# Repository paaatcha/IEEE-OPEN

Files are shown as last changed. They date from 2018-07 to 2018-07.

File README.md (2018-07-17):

# IEEE OPEN

The IEEE OPEN is a category of the Latin American Robotic Competition (LARC) in which is allowed to use anything in order to solve a given challenge. In 2013, I led a team with 9 students that participated in this competition in Arequipa, Peru. The competition's rule is described in [this document](). In brief, we needed to develop an **autonomous beach cleaner robot**. This robots had to perform in the simulated arena depicted below:

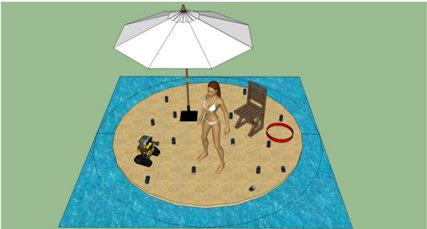
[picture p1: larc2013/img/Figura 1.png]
arena


The robot was entirely designed on the 3D software [OpenScad](http://opensacad.org) and its physical structure was composed of acrylic and 3D printed pieces. In [estrutura folder](https://github.com/paaatcha/IEEE-OPEN/tree/master/larc2013/estrutura) you can see all designed parts.

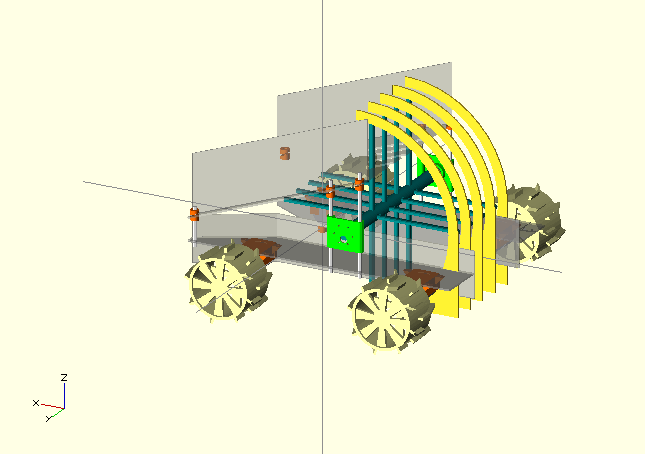
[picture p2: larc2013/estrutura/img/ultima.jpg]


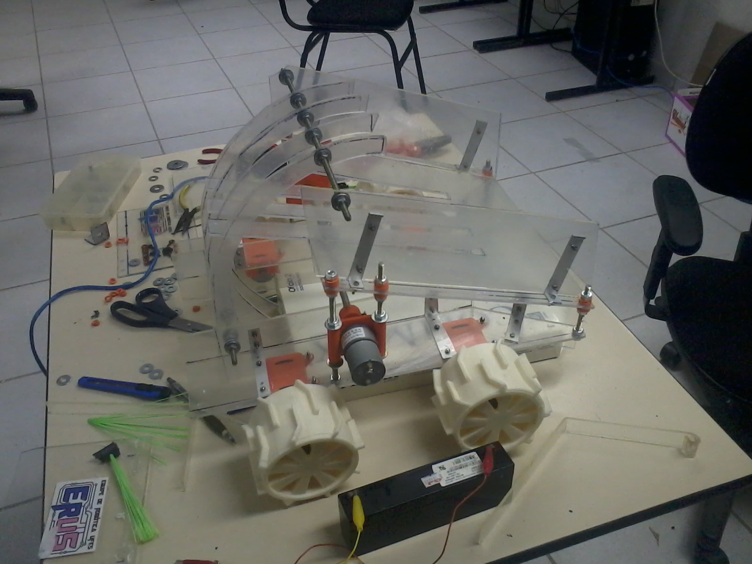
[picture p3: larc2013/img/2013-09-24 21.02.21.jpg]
real


In order to "see" the environment, we used an Android smartphone embedded in the robot and all computer vision was processed on the own Android. We needed to do it for two main reasons: first, we didn't have money to afford a good camera; second, it was an elegant solution since the smartphone fitted perfectly in the robot. To control motors, servo motors, and ultrasonic sensors, we used an Arduino Mega. In brief, the working flow was: the Android gets information for the world through its camera, process it and send the commands to the Arduino. 

To put everything together, we developed a PCB that you can find on [eletronica folder](https://github.com/paaatcha/IEEE-OPEN/tree/master/larc2013/eletronica).

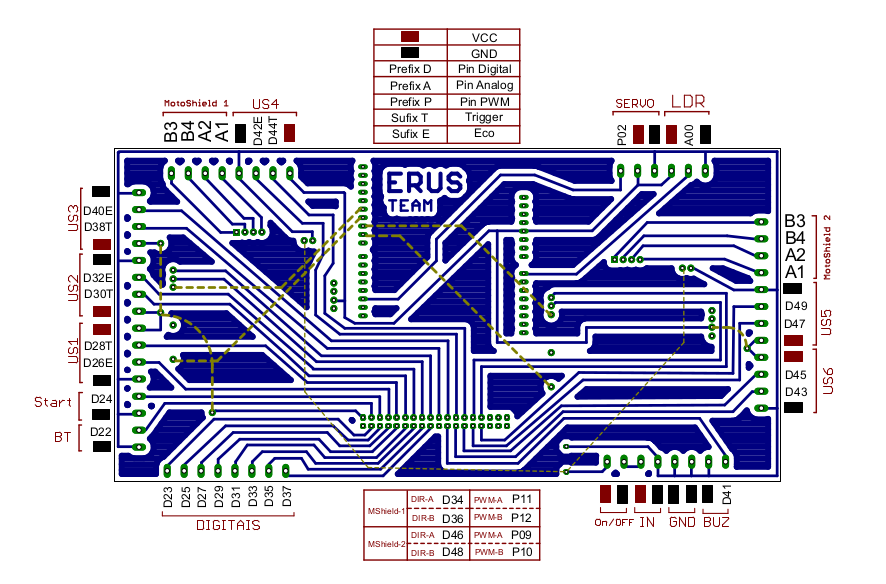
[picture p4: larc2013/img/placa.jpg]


All code developed to this project is avalaible on [programacao folder](https://github.com/paaatcha/IEEE-OPEN/tree/master/larc2013/programacao). We used C/C++ and Java to programmed all parts.

A curious and sad thing that happened to us when we were traveling to Peru was that the airplane company has lost our luggage with many parts of the robot. Therefore, a day and a half before the competition starts, we needed to reconstruct the whole robot from almost scratch. Luckily, all electronic parts arrived, however, we've lost some motors. What we did was buy a lot of things in the local market to reconstruct the robot. Even with this, we were able to get the 2nd place out of 19 teams. No doubt, it was the most exciting story of my life.

The robot version at the competition:

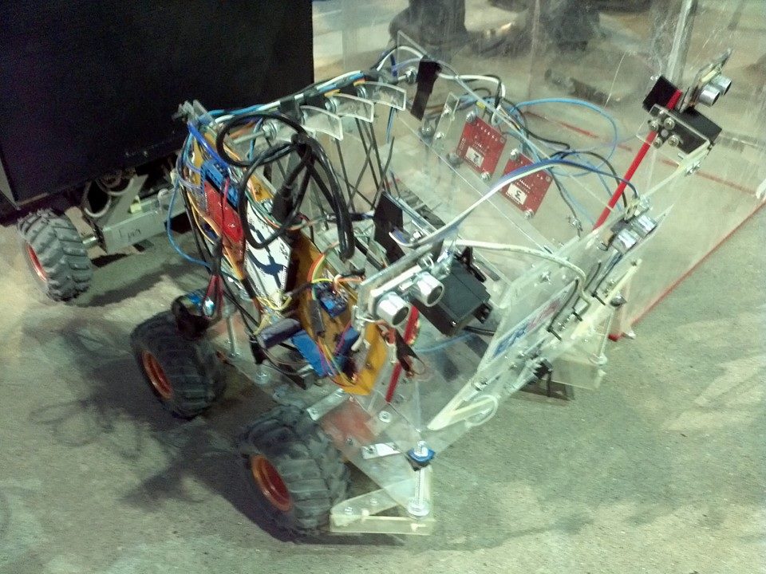
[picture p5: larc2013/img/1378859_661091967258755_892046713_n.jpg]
robo


The team after the 2nd place in the competition:

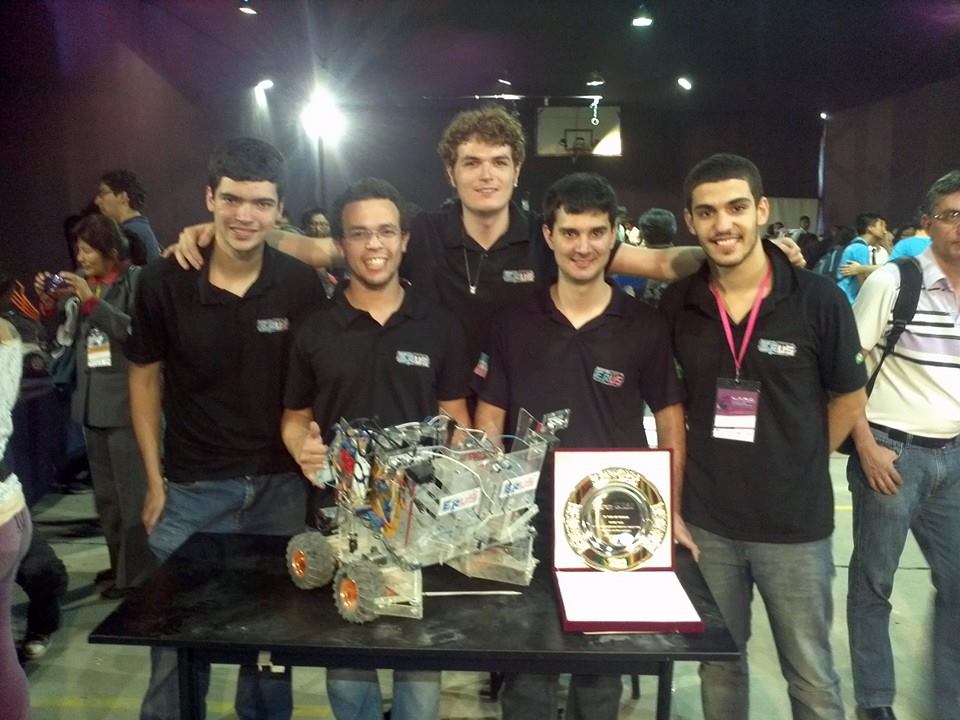
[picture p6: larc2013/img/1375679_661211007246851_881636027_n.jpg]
team


Take a look at the robot perfoming in the competition:

IMAGE ALT TEXT HERE (https://www.youtube.com/watch?v=20euAUzxxZE)

We got famous in our city. Take look at our interview to a local news:

IMAGE ALT TEXT HERE (https://www.youtube.com/watch?v=20b5NIf7TLY)

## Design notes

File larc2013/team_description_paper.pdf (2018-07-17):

ERUS – TEAM DESCRIPTION PAPER – IEEE OPEN 2013

ROBERTA LIMA GOMES¹

, ANDRÉ GEORGHTON CARDOSO PACHECO 1

, LUCAS CATABRIGA ROCHA¹

, JUAN FRANÇA MUNIZ DE
SOUZA¹

, EBENÉZER NOGUEIRA DA SILVA¹

, GUILHERME ARTÉM DOS SANTOS¹

, VANDERLEI VIEIRA DE SOUZA FILHO¹

, RENAN
SARCINELLI¹

, IGOR OLIVEIRA NUNES¹

, THAYLO XAVIER DE FREITAS¹

Departamento de Informática ¹

Centro Tecnológico, Universidade Federal do Espírito Santo Av. Fernando Ferrari 514 – Goiabeiras, Vitória ES

Abstract This article reports the work of the team ERUS building a robot to solve the challenge posed in IEEE Open 2013 category. The robot collects empty cans on an irregular terrain made of sand and deposits them in a trash bin. The system built uses an Android phone connected to an Arduino board.

Keywords Robotics, Android, Arduino.

Resumo Este artigo relata o trabalho desenvolvido pela equipe ERUS na construção de um robô para solucionar o desafio proposto na categoria IEEE Open 2013. O robô construído coleta latas de refrigerante em um terreno irregular feito de areia e as deposita em uma lixeira. O sistema construído é composto por um celular Android conectado a uma placa Arduino.

Palavras-chave Robótica, Android, Arduino, LARC.

### 1 Introdução

O desafio IEEE OPEN 2013 proposto na Competição Latino Americana de Robótica (em inglês Latin American Robotics Competition abreviado por LARC) tem como temática a limpeza de resíduos em uma praia. A arena da competição consiste em uma circunferência de areia cercada por uma região azul que representa o mar, simulando assim uma ilha. Nesta arena um robô, completamente autônomo, deverá coletar latas de alumínio espalhadas pela mesma e depositá-las em uma lixeira também localizada na arena. O robô não poderá tocar em nenhum obstáculos presentes na arena, obstáculos estes que serão: uma cadeira, uma sombrinha de praia e um manequim. Além disso o robô não pode adentrar a região azul, que representa o mar. Caso descumpra uma das normas acima, a equipe sofrerá punições na pontuação final e/ou sofrerá reinício da rodada.
A Equipe ERUS (Equipe de Robótica da Universidade Federal do Espírito Santo), formada por alunos de engenharias da UFES, desenvolveu um robô para solucionar este desafio. O robô, completamente projetado em softwares de desenvolvimento 3D, foi desenvolvido para navegar em ambiente com terreno irregular, assim como os terrenos existentes em praias. Sua estrutura física é composta, principalmente, por peças de acrílico e plástico. A parte eletrônica do robô é composta por um Arduino Mega ADK que se comunica com um celular com sistema operacional Android. Este celular é utilizado como “cérebro” central do robô. Nele são capturadas e processadas as imagens da arena. Para isso, as linguagens de programação utilizadas foram C, C++ e Java.
A seguir são apresentados mais detalhes sobre o desafio e as tecnologias utilizadas no desenvolvimento do robô.

### 2 Objetivo

Este desafio tem como objetivo a construção e programação de um robô que trabalhe de forma completamente autônoma. O robô deve ser capaz de identificar todos os objetos inclusos, tais como: Cadeira, sombrinha, manequim, lixeira e latas. Uma vez identificado o obstáculo, o robô deve possuir inteligência suficiente para discernir quais destes objetos são obstáculos e quais são lixo. Além disso, o robô deverá navegar somente dentro do espaço permitido na arena, ou seja, na areia, e coletar o máximo de latas encontradas. Após coletadas, as mesmas deverão ser depositadas em um lugar específíco demarcado na arena.

### 3 Considerações do Ambiente

O cenário proposto simula uma ilha. Para isso, é construído uma arena, com forma circular, cujo as bordas são demarcadas pela cor azul. O tamnaho total da arena possui 6 metros quadrados. Destes, 5,5 metros quadrados são preenchidos por areia. O restante representa o mar e será preenchido por um material de cor azul.
Como já mencionado, a arena deverá conter latas de alumínio, pintadas de preto, que representarão o lixo da praia (que serão colocadas de forma aleatória por toda a arena); um manequim, que representará um banhista; uma cadeira e um guarda sol, que representarão o material utilizado pelo banhista; e por fim uma bandeja circular vermelha, que representará um depósito de lixo onde as latas de alumínio deverão ser recolhidas e depositadas pelo robô.
Um esboço da arena é representado na figura 1:

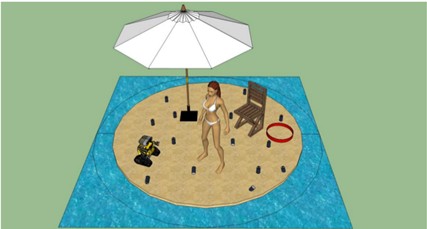
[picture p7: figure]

Figura 1: Arena e seus objetos

Um fator extremamente importante a ser considerado no ambiente é luminosidade do local. A arena poderá estar tanto em um ginásio aberto, e exposta ao sol, quanto em um ginásio fechado. Portanto fica a cargo da equipe solucionar este problema.

### 4 Desenvolvimento do robô

A seguir será apresentado todo o desenvolvimento do robô divido em três partes: Estrutura, Eletrônica e Programação.

4.1 Estrutura do robô
A primeira parte projetada na contrução do robô foi a sua estrutura. Para auxiliar nesta fase, foram utilizados softwares de modelagem 3D como OpensCad [1] e SolidWorks [2]. Portanto, toda estrutura do robô antes de ser físicamente construída foi modelada em 3D para se obter uma melhor performace na construção.

Vale a pena ressaltar que algumas das peças modeladas nos softwares citados acima foram impressas para facilitar a construção física da estrutura. Isso apenas intensifica a importância de uma modelagem 3D antes da construção física.

A estrutura física do robô possui basicamente 3 partes principais: garra, caçamba e a base. Cada uma destas partes será brevemente detalhadas a seguir:
- Garra: A garra do robô consiste, basicamente, em uma “vassoura”. A ideia é que o robô possa “varrer” as latas encontradas para dentro de sua caçamba, para posteriormete depositá-las na lixeira. A garra foi construída utilizando acrílico e peças 3D modeladas e impressas. Para movimentar a garra é utilizado apenas um motor.
- Caçamba: Com intuito de armazenar as latas antes das mesmas serem depositadas, a caçamba do robô foi contruída utilizando acrílico. Esta caçamba foi modelada e con-
truída com uma inclinação de | 20º | para que
possa ser aproveitada a gravidade para as latas caírem. Sendo assim, o único movimento necessário para depositar as latas é abrir a comporta traseira que as prendem. Para isso é utilizado um servo motor que realiza o movimento necessário para abrir e fechar a comporta.
- Base: Toda base do robô também foi construída com acrílico. A base sustenta toda estrutura do robô, como a caçamba e a garra citadas acima. Também, nela, são posicionados toda eletrônica, motores e celular pertinentes ao robô.

Como o robô deverá se movimentar em terreno irregular, ele foi construído com tração 4x4 para evitar que o mesmo fique preso em alguma irregularidade da arena.

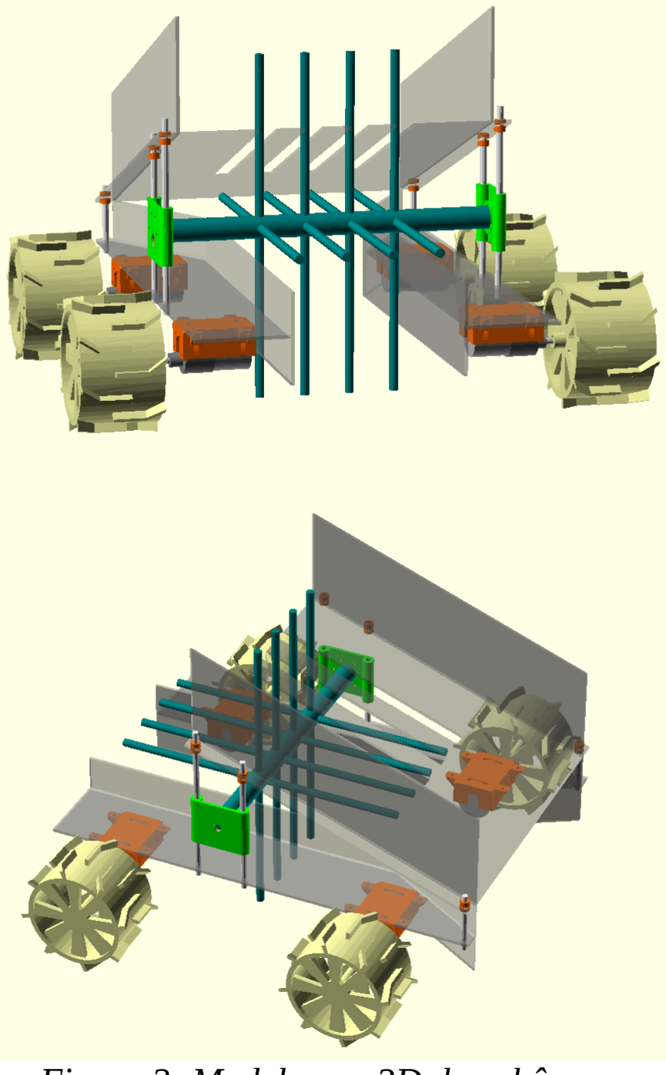
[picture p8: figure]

Figura 2: Modelagem 3D do robô

4.2 Eletrônica
Paralelamente a estrutura, foi desenvolvido toda eletrônica do robô. Para controlar o robô foram utilizados um Arduino Mega ADK [3] e um Celular com Android [4] conectados. A ideia principal é processar a imagem do ambiente no Android e, baseado, nesse processamento enviar as informações para Arduino para que este comande os movimentos do robô.

4.2.1 Arduino
Como já mencionado foi utilizado um microprocessador Arduino Mega ADK para realizar as operações de baixo nível necessárias para o funcionamento do robô. A grande vantagem deste microcontrolador é que ele já implementa uma interface de comunicação USB evitando, assim, a utilização de um shield USB [5] para a comunicação com o Android.
O Arduino é responsável por controlar todos os motores, servo motor, sensores de distância, bem como os botões de on/off e start. Sendo assim, para movimentação dos motores elétricos foi necessário a utilização de duas pontes H, definindo assim a direção dos mesmos.
O controle executado pelo Arduino sofre forte influência das informações de imagens processadas pelo Android. De certo modo, pode-se afirmar que existe uma relação de Mestre e Escravo entre o Arduino e o Android. O Arduino obedece os comandos enviados pelo Android, podendo apenas realizar interrupções geradas pelos sensores de distância, caso o mesmo consiga detectar um obstáculo não encontrado pela câmera.

4.2.2 Android
Aparelhos celulares modernos possuem grande poder de processamento, além disso possuem vários sensores embutidos, como uma câmera de vídeo, bússola e acelerômetro. Isto cria uma ambiente poderoso para o desenvolvimento de robôs móveis e por conta disso este sistema foi escolhido pela ERUS como sistema principal a ser utilizado no robô. O celular utilizado foi um Motorola Milestone I, rodando Android v2.2.
O Android recebe periodicamente valores dos sensores de bússola e acelerômetro além de processar a imagem capturada pela câmera de vídeo existente no celular. De acordo com as informações processadas, o Android envia as ordens para o Arduino por meio de uma troca de informações e um protocolo criado pela equipe.

4.3 Programação
Nesta seção será apresentado tudo o que tange a programação no desenvolvimento do robô. Fica a cargo da programação o controle do Android e do Arduino e a comunicação de ambos. Além disso, aqui é criada uma interface de comunicação entre o Android e um computador, denominado Fiscal. Como o próprio nome sugere, o Fiscal é utilizado como uma fonte de auxílio para depuração de erros e deve se deixar bem claro que essa funcionalidade não é utilizada durante a execução oficial do robô, que funciona de maneira completamente autônoma. Para criar todas as funcionalidade citadas acima, foi necessário desenvolvimento nas seguintes linguagens de programação: C e C++, para o desenvolvimento no Arduino, e Java, para desenvolvimento no Android e Fiscal.

4.3.1 Comunicação Arduino - Android
A comunicação entre o Arduino e o Android ocorre através de um cabo USB. Essa comunicação é facilitada pelo fato do modelo do Arduino utilizado já realizar uma interface de comunicação USB sem necessidade de eletrônica adicional.
O celular Android suporta o ADB (em inglês Android Debug Bridge) [6], uma ferramenta capaz de se comunicar com o Android através da interface USB. Para que o Arduino seja capaz se de comunicar com o ADB, é necessário implementar um protocolo de comunicação em baixo nível. Este protocolo é implementado pela biblioteca MicroBridge
[7] e, portanto, foi utilizada no código de comunicação entre as duas tecnologias.
Nesta configuração a conexão é vista como uma conexão padrão através de um Socket pelo código que roda no Android. No Arduino, a conexão é realizada através de funções da MicroBridge. Além do protocolo implementado pela MicroBridge, é necessário, ainda, um outro protocolo de comunicação básico, porém, mais alto nível. Este último protocolo foi elaborado para que mensagens fossem trocadas entre o Android e o Arduino.

4.3.2 Comunicação Android – Computador
Como já descrito, esta conexão não é utilizada no momento da competição, e sim na depuração de erros, monitoramento dos sensores do robô durante os treinos e calibração de valores. Decidiuse implementar esta funcionalidade para facilitar o desenvolvimento e acelerar a calibração de valores. É possível gravar dados de calibração em um cartão SD no celular através da conexão com o computador e, assim, quando o robô estiver operando autonomamente o cartão SD é lido e os últimos dados enviados pelo computador são utilizados. Também é possível executar o robô em um modo de monitoramento, no qual todos os valores de sensores e variáveis importantes são enviadas ao computador, sendo possível observar possíveis falhas em tempo real.
Para esta finalidade foi desenvolvida, em Java, uma interface gráfica de monitoramento denominada Fiscal. O meio utilizado para esta comunicação é a interface Wireless disponível no celular e em computadores. O protocolo utilizado é o mesmo que protocolo criado para troca de mensagens entre o Arduino e o Android, sendo que algumas mensagens podem ser repassadas desde o Arduino até o computador e vice-versa.

4.3.3 Visão Computacional

A visão computacional é toda realizada dentro do celular Android. Entretanto, o Android não possui nenhuma biblioteca para tratamento de imagens. Sendo assim, se fez necessário a utilização da biblioteca OpenCV para Android [8].
Para o processamento da imagem, é necessário a implementação de algoritmos que identifiquem os objetos que estão na arena. Para auxiliar neste ponto, a equipe utilizou o Color Blob Detector, um algoritmo que é capaz de detectar as diferentes cores nas imagens.
Inicialmente, ao se receber a imagem, é realizada uma conversão de RGB para HSV para facilitar o processamento da mesma. São especificadas as cores a serem reconhecidas a um raio mínimo préestabelecido. Após a identificação é retornado a imagem com os objetos detectados atraveś de um contorno.
Identificado o ambiente, o Android deve tomar decisões sobre o mesmo: Continuar a explorar, coletar lata, depositar lata, dentre outras decisões possíveis. Tomada essa decisão, uma mensagem de ordem é enviada ao Arduino e logo após executada pelo robô.

### 5 Conclusão

Com o avanço da tecnologia, os celulares estão se tornando mais poderosos, em nível de processamento, e também cada vez mais completos, visto que neles há inserção de vários sensores. O uso integrado de celulares com sistemas operacionais, como o Android, e microcontroladores, como o Arduino, demostrou ser bastante eficiente e confiável para o desenvolvimento de robótica autônoma. Além disso, a utilização de um celular também demostrou ser uma opção com um ótimo custo benefício, devido ao fato do mesmo já possuir diversos sensores que se fossem adquiridos de forma separada aumentaria, e muito, o custo total do projeto. Por fim, pode-se afirmar, devido aos fatos já expostos, que a a robótica tem se tornado mais acessível para a maioria das pessoas.

Referências Bibliográficas

[1] http://www.openscad.org/
[2] http://www.solidworks.com/
[3] http://arduino.cc/en/Main/ArduinoBoardADK
[4] http://www.android.com/

[5]http://www.circuitsathome.com/products-page/ar-
| duino-shields/usb-host-shield-2-0-for-arduino (http://www.circuitsathome.com/products-page/arduino-shields/usb-host-shield-2-0-for-arduino)
[6] http://developer.android.com/tools/help/adb.html
[7] http://code.google.com/p/microbridge/
[8] http://opencv.org/platforms/android.html

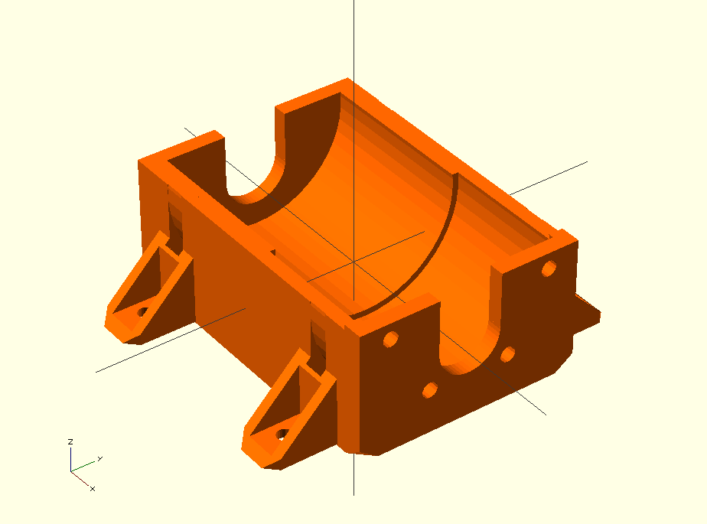
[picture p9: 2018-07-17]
larc2013/estrutura/img/suporteMotor.png

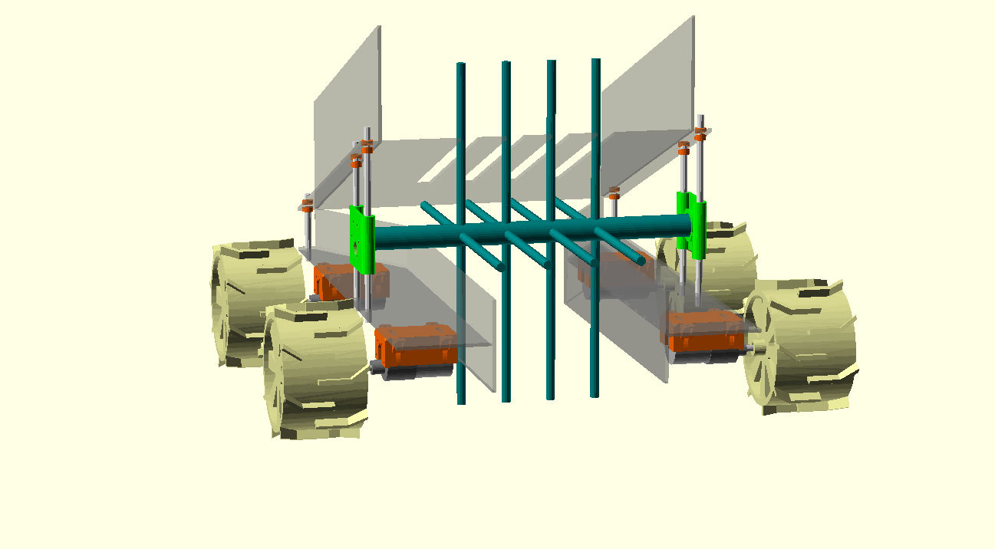
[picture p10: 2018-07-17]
larc2013/img/1498749_768988053135812_4544890504547737136_o.png

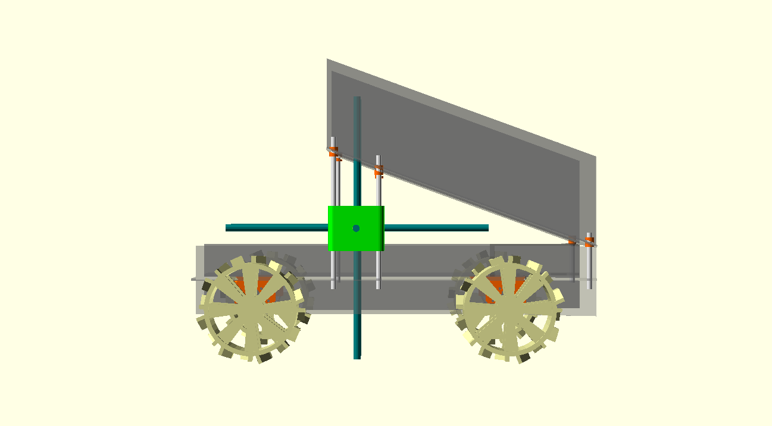
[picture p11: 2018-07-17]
larc2013/estrutura/img/polipo2.png

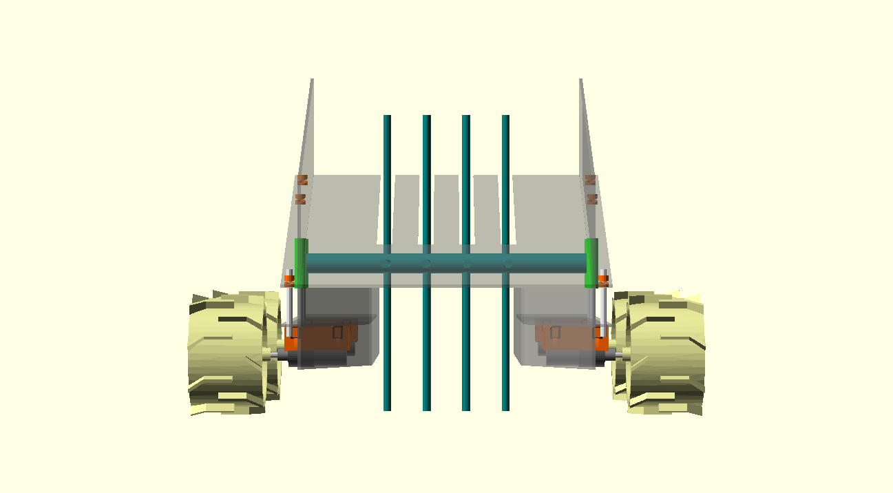
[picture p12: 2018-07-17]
larc2013/estrutura/img/polipo3.png

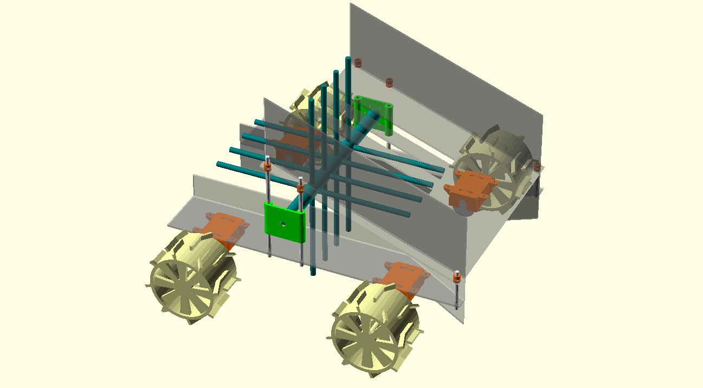
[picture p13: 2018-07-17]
larc2013/estrutura/img/polipo7.png

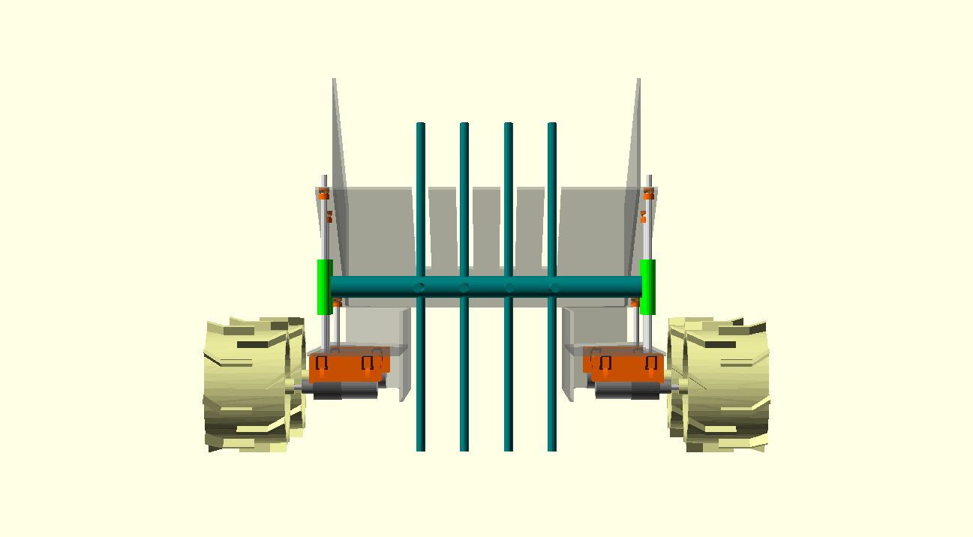
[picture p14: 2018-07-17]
larc2013/estrutura/img/polipo4.png

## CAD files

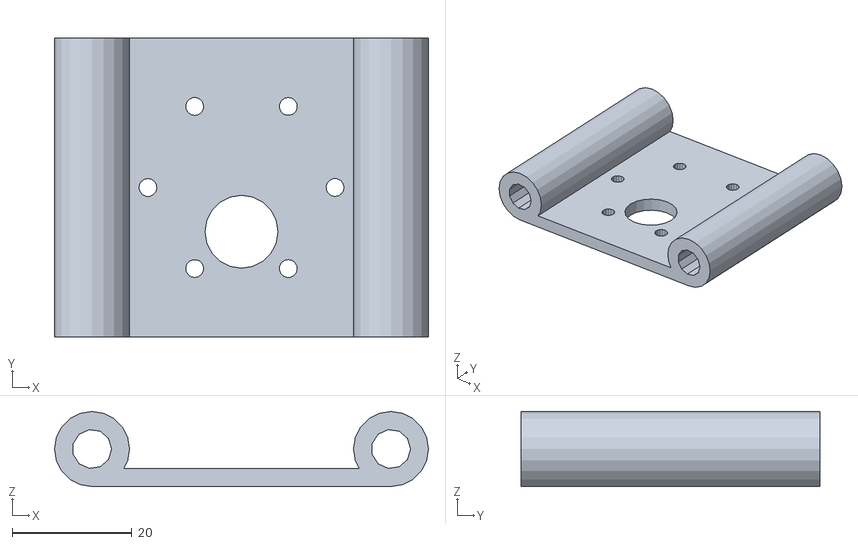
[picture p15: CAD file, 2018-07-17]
larc2013/estrutura/suporteMotorVassoura.stl
62.5 x 50.0 x 12.6

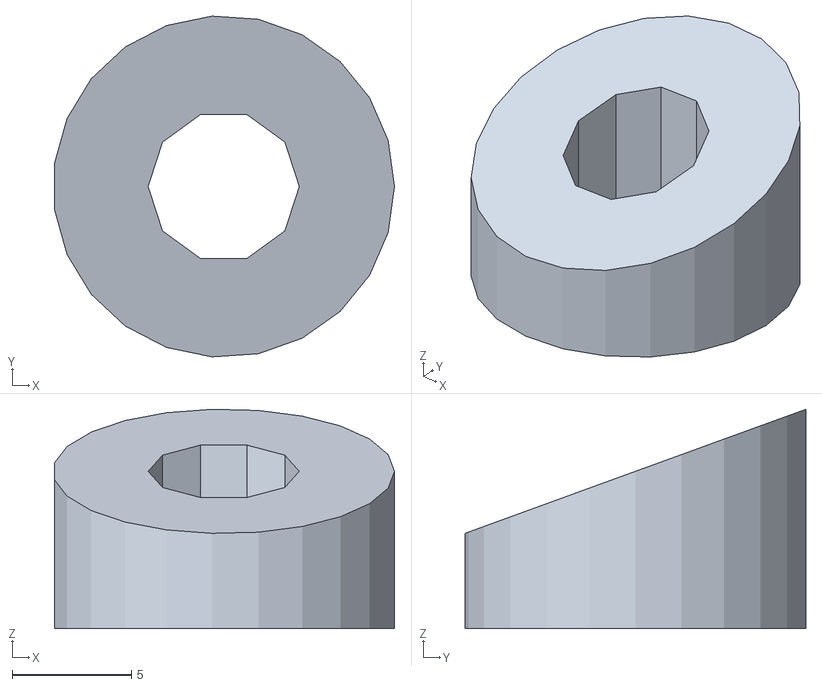
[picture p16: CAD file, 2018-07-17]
larc2013/estrutura/arruelaInclinada.stl
14.3 x 14.3 x 9.22

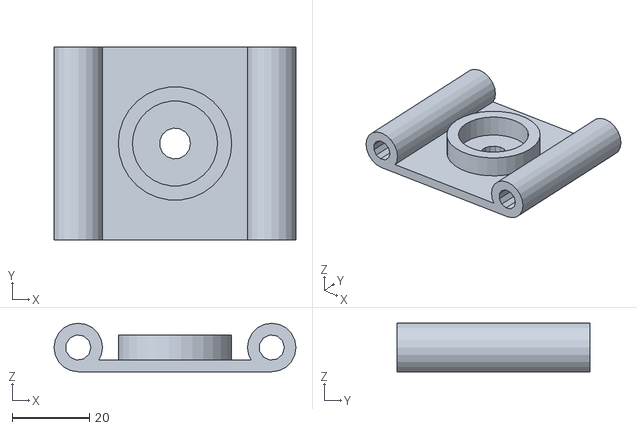
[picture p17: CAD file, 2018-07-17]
larc2013/estrutura/suporteRolamentoVassoura.stl
62.5 x 50.0 x 12.6

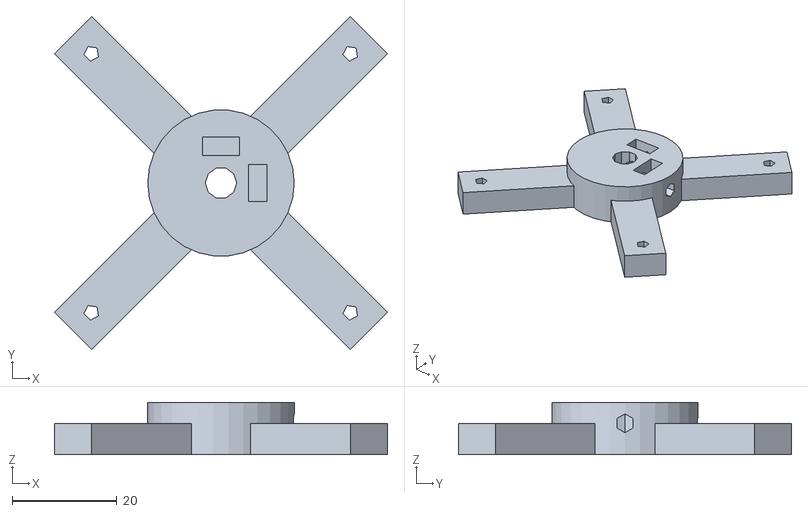
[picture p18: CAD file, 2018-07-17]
larc2013/estrutura/wheelAdapter.stl
63.6 x 63.6 x 10.0

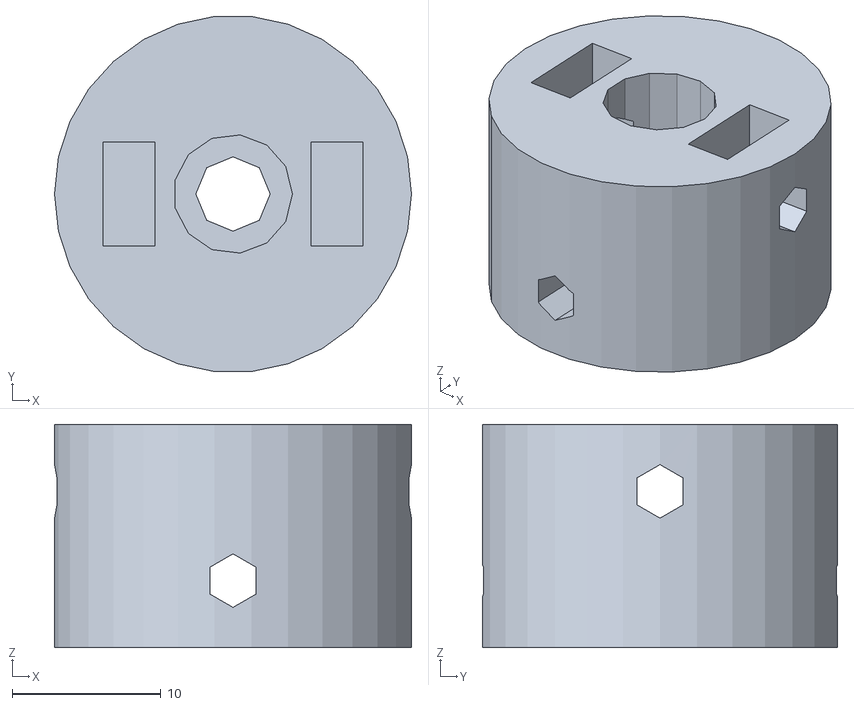
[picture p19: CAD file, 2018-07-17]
larc2013/estrutura/AxisConnector.stl
24.0 x 23.9 x 15.0

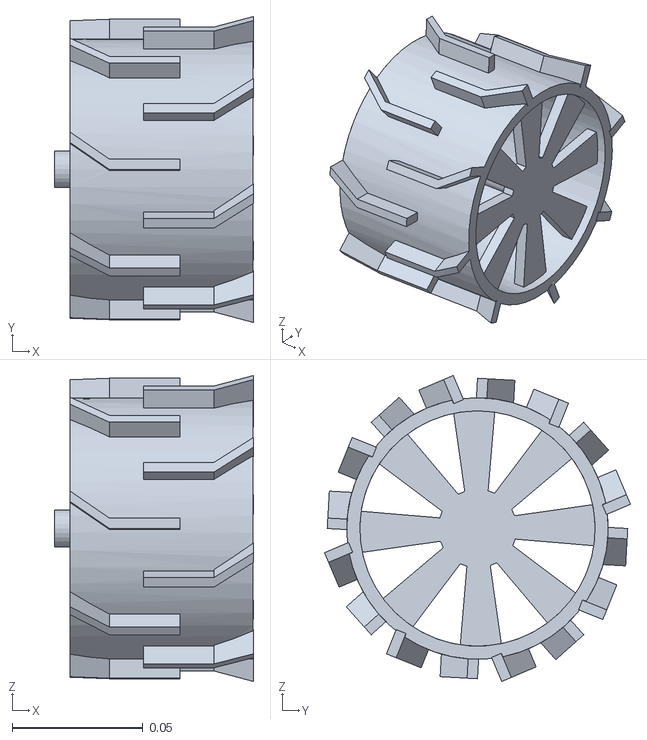
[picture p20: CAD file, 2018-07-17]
larc2013/estrutura/Roda.stl
0.0761 x 0.117 x 0.117

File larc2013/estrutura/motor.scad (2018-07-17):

include <medidas.scad>

motorLength= MOTOR_LENGTH1 + MOTOR_LENGTH2; 
motorShaftDisplacement= [-7.4, 0 , motorLength/2]; 

module motor()
{
	color([0.7,0.7,0.7])
	{
		translate([0,0,MOTOR_LENGTH1/2])
		{
			cylinder(h = MOTOR_LENGTH2+0.015, r = MOTOR_DIAMETER2/2.0, center = true, $fn=50);
		}
	}
	color([0.5,0.5,0.5])
	{
		translate([0,0,-MOTOR_LENGTH2/2])
		{
			cylinder(h = MOTOR_LENGTH1, r = MOTOR_DIAMETER1/2.0, center = true, $fn=50);
		}
	}

	color([0.5,0.5,0.5])
	{
		scale([1,1,-1])
		{
			translate(motorShaftDisplacement)
			{
				cylinder(h = MOTOR_SHAFT_LENGTH, r = MOTOR_LARGE_SHAFT_DIAMETER/2, center=true, $fn=25);
			}
		}
	}

		color([0.8,0.8,0.8])
	{
		scale([1,1,-1])
		{
			translate(motorShaftDisplacement+[0,0,MOTOR_SHAFT_LENGTH])
			{
				eixo();
			}
		}
	}
}

module eixo ()
{
	rotate([0,0,360*$t])
	{
		difference()
		{
			cylinder(h = MOTOR_BIGGER_SHAFT_LENGTH, r = MOTOR_SHAFT_DIAMETER/2, center=true, $fn=20);
			translate([MOTOR_SHAFT_DIAMETER_CUT,0,0])
			{
				cube([MOTOR_SHAFT_DIAMETER,MOTOR_SHAFT_DIAMETER,1.1*MOTOR_BIGGER_SHAFT_LENGTH], center=true);
			}
		}
	}
}

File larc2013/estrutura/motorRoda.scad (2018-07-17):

include <motor.scad>
include <suporteMotor.scad>
include <medidas.scad>

module suporteMotor ()
{
	motormount();
	translate([-MOTOR_DIAMETER1/4,0,0])
	rotate([0,180,180])
	{
		motor();
	}
}

module motorRoda()
{
	suporteMotor();
	translate([-MOTOR_DIAMETER1/4-7.4,0,(MOTOR_LENGTH1+MOTOR_LENGTH2)/2+MOTOR_BIGGER_SHAFT_LENGTH/2+WHEEL_WIDTH/2])
	{
		rotate([-90-360*$t,-90,0])
		{
			scale([1000,1000,1000])
			{
				color([0.9,0.9,0.6])
				{
					import ("Roda.stl");
				}
			}
		}
	}
}

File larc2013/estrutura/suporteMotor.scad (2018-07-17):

include <medidas.scad>

diameter = MOTOR_DIAMETER1;
diameter2 = MOTOR_DIAMETER2;
diameterLength = MOTOR_LENGTH1;
diameter2Length = MOTOR_LENGTH2;
shaftLength = MOTOR_SHAFT_LENGTH;
suporteMotorLength = diameterLength + diameter2Length; 
shaftDiameter = MOTOR_SHAFT_DIAMETER;
largeShaftDiameter = MOTOR_LARGE_SHAFT_DIAMETER;
suporteMotorShaftDisplacement = [-7.4, 0 , suporteMotorLength/2]; 
screwDiameter = MOTOR_SCREW_SUPORT_DIAMETER;
screw2Diameter = MOTOR_SCREW_MOTOR_DIAMETER;
pinDiameter = 20;
pinHeight = 10;
zipLockThickness = MOTOR_ZIPLOCK_THICKNESS;
zipLockWidth = MOTOR_ZIPLOCK_WIDITH; 

module motormount()
{	
	color([1,0.4,0])
	{
		difference()
		{
			union()
			{
				rotate([0,180,0])
				{
					difference()
					{
						union()
						{
							rotate([0, 90, 0])
							{
								printCube(suporteMotorLength +6, diameter+5,(diameter/2) +5 , 5);
							}
							translate([diameter/2-8,0,-suporteMotorLength/2-1])
							cube([4,diameter+5,4],center=true);
						}
						translate([10, 0, 0])
						{
							motorSpace();
						}
					}
				}
	
				screwSupport(-20);
				screwSupport(20);
			}
			translate([-10,0,20])
			{
				ring((diameter/2)+2.5, zipLockThickness, zipLockWidth);
			}
			translate([-10,0,-20])
			{
				ring((diameter/2)+2.5, zipLockThickness, zipLockWidth);
			}
		}
	}
}

module ring(radius, thickness, width)
{
	difference()
	{
		cylinder(r= radius+thickness, h = width, center=true, $fn=50);
		cylinder(r= radius, h= width*2, center=true, $fn=50);
	}
}

module uHole(radius, height)
{
	cubeLength = 1000;
	cylinder(h = height, r = radius, center=true, $fn=50);
	translate([cubeLength/2, 0, 0])
	{
		cube([cubeLength, 2*radius, height], center=true);
	}
}

module triangle(cateto, width)
{
	rotate([0, 0, 90])
	{
		difference()
		{
			cube([cateto, cateto, width], center = true);

			translate([cateto/2, cateto/2, 0])
			{
				rotate([0, 0, 45])
				{
					cube([cateto*sqrt(2), cateto*sqrt(2), width+1], center=true);
				}
			}
		}
	}
}

module screwSupportTriangle(z)
{
	translate([5.25, diameter-10, z])
	{
		triangle(13, 10);
	}

	scale([1,-1,1])
	{
		translate([5.25, diameter-10, z])
		{
			triangle(13, 10);
		}
	}
}

module screwSupportCube(z)
{
	translate([0, diameter-15, z-3])
	{
		cube([10, 10, 6]);
	}

	scale([1,-1,1])
	{
		translate([0, diameter-15, z-3])
		{
			cube([10, 10, 6]);
		}
	}
}
module screwSupportCylinder(z)
{
	translate([0, diameter-10, z])
	{
		rotate([0, 90, 0])
		{
			cylinder(h = 15, r = screwDiameter/2, $fn=20);
		}
	}
	scale([1,-1,1])
	{
		translate([0, diameter-10, z])
		{
			rotate([0, 90, 0])
			{
				cylinder(h = 15, r = screwDiameter/2, $fn=20);
			}
		}
	}
}

module screwSupport(z, screwDiameter)
{
	difference()
	{
		difference()
		{
			screwSupportTriangle(z);
			screwSupportCube(z);
		}
		translate([0,0,-0.3])
		{
			rotate([45,45,-135])
			{
				cube([d,d,d], center =true);
			}
		}
		
		screwSupportCylinder(z);
		
		translate([0,((diameter+5)/2)+13,-5+z])
		{
			rotate([45,0,0])
			{
				cube([300,3,3], center =true);
			}
		}
			
		translate([0,((diameter+5)/2)+13,5+z])
		{
			rotate([45,0,0])
			{
				cube([300,3,3], center =true);
			}
		}

		translate([0,-((diameter+5)/2)-13,-5+z])
		{
			rotate([45,0,0])
			{
				cube([300,3,3], center =true);
			}
		}
			
		translate([0,-((diameter+5)/2)-13,5+z])
		{
			rotate([45,0,0])
			{
				cube([300,3,3], center =true);
			}
		}
	}
}

module motorSpace()
{
	translate([0,0,diameterLength/2])
	{
		cylinder(h = diameter2Length+0.015, r = diameter2/2.0, center = true, $fn=50);
	}

	translate([0,0,-diameter2Length/2])
	{
		cylinder(h = diameterLength, r = diameter/2.0, center = true, $fn=50);
	}

	color([1.0,0,0])
	{
		translate(suporteMotorShaftDisplacement)
		{
			uHole(radius=largeShaftDiameter/2, height=10);
		}

		scale([1,1,-1])
		{
			translate(suporteMotorShaftDisplacement)
				{
					uHole(radius=largeShaftDiameter/2, height=10);
				}
		}
		for(i=[1:6])
		{
		rotate([0,0,60*i])
			{
				translate([0,15.65,-diameter2Length])
				{
				cylinder (r=screw2Diameter/2,h= diameterLength,center=true,$fn=15);
				}
			}	
		}
	}
}

module printCube(a,b,c,d)
{
	translate([a,b,c]/-2)
	difference()
	{
	cube([a,b,c]);
	
	translate([0,0,-0.2*d])
	rotate([45,45,-135])
	cube([d,d,d], center =true);

	translate([0,b,-0.2*d])
	rotate([45,45,135])
	cube([d,d,d], center =true);

	translate([a,b,-0.2*d])
	rotate([45,45,45])
	cube([d,d,d], center =true);

	translate([a,0,-0.2*d])
	rotate([45,45,-45])
	cube([d,d,d], center =true);
	}
}

rotate([0,90,0])
motormount();

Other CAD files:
larc2013/estrutura/suporteMotorVassoura.scad
larc2013/estrutura/AxisConnector.scad
larc2013/estrutura/Polipo.scad
larc2013/estrutura/RodaRefletida.scad
larc2013/estrutura/arruelaInclinada.scad
larc2013/estrutura/base.scad
larc2013/estrutura/bigBattery.scad
larc2013/estrutura/halfMoon.scad
larc2013/estrutura/halfMoon3D.scad
larc2013/estrutura/half_moon.scad
larc2013/estrutura/half_moon_3D.scad
larc2013/estrutura/inclinacao.scad
larc2013/estrutura/medidas.scad
larc2013/estrutura/paredeBase.scad
larc2013/estrutura/rampa.scad
larc2013/estrutura/smallBattery.scad
larc2013/estrutura/suporteRolamentoVassoura.scad
larc2013/estrutura/vassoura.scad
larc2013/estrutura/wheelAdapter.scad

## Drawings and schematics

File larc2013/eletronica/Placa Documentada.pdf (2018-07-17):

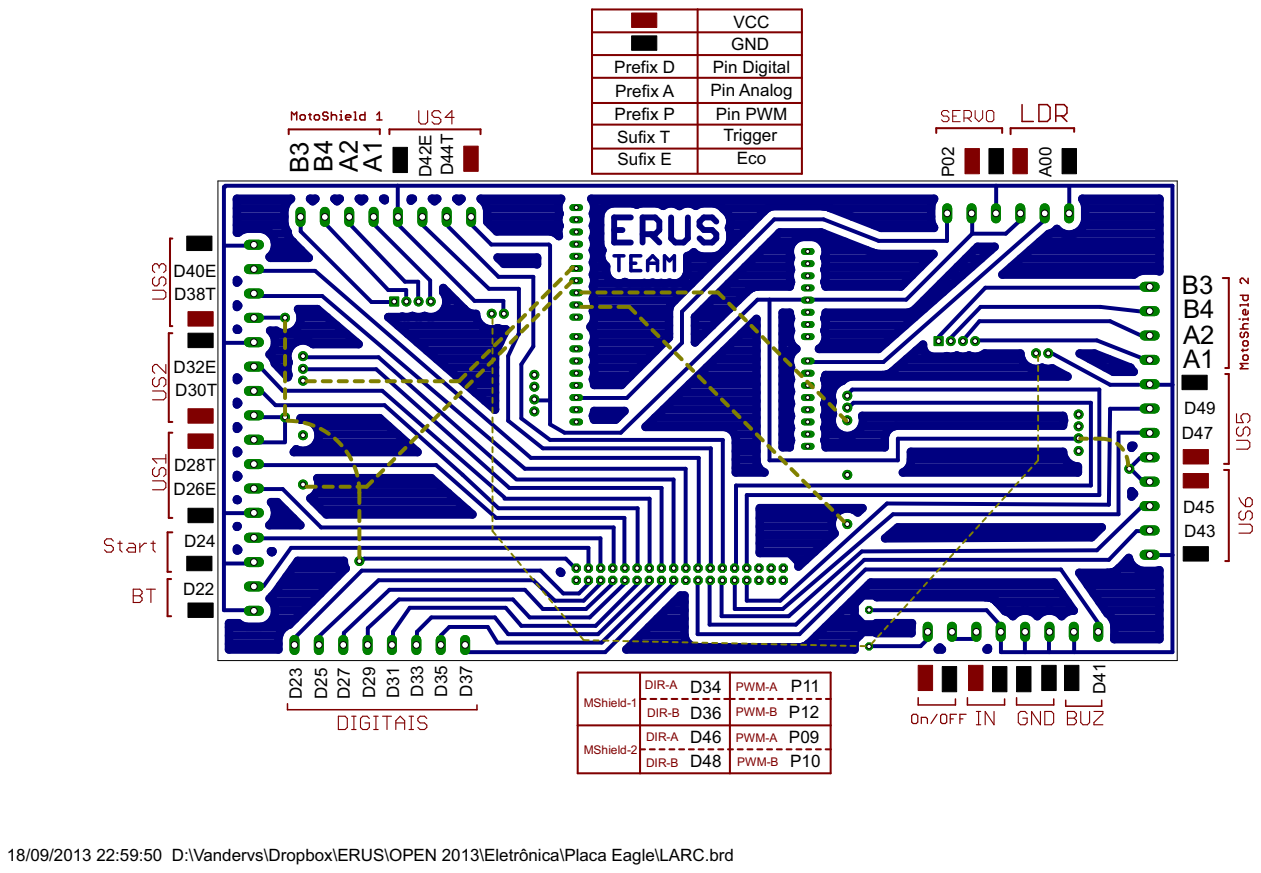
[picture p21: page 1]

VCC
GND

Prefix D | Pin Digital
Prefix A | Pin Analog
Prefix P | Pin PWM
Sufix T | Trigger
Sufix E | Eco

MShield-1 | DIR-A D34 DIR-B D36 | PWM-A P11 PWM-B P12

MShield-2 | DIR-A D46 D48 DIR-B | PWM-A P09 P10 PWM-B

18/09/2013 22:59:50 D:\Vandervs\Dropbox\ERUS\OPEN 2013\Eletrônica\Placa Eagle\LARC.brd

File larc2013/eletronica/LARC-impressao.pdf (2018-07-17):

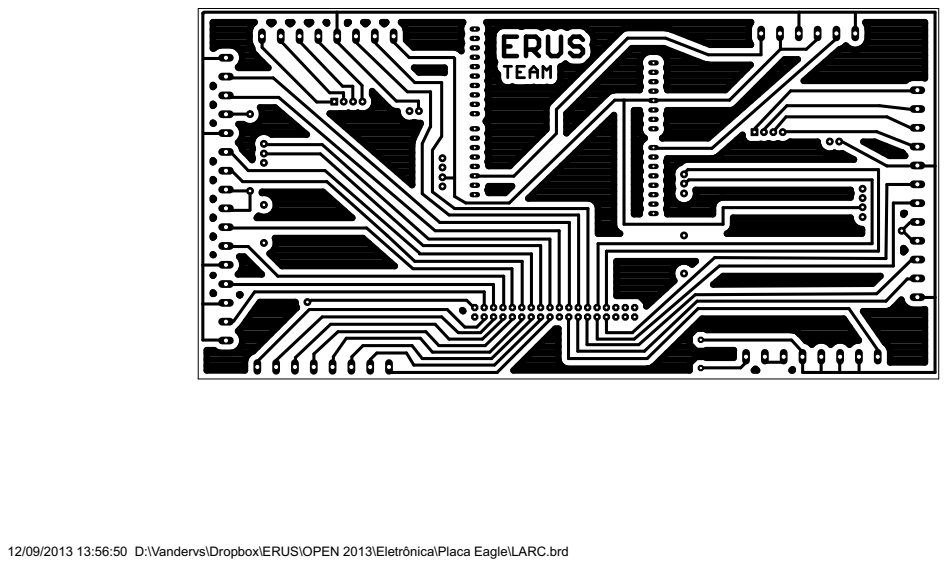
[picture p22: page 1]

12/09/2013 13:56:50 D:\Vandervs\Dropbox\ERUS\OPEN 2013\Eletrônica\Placa Eagle\LARC.brd

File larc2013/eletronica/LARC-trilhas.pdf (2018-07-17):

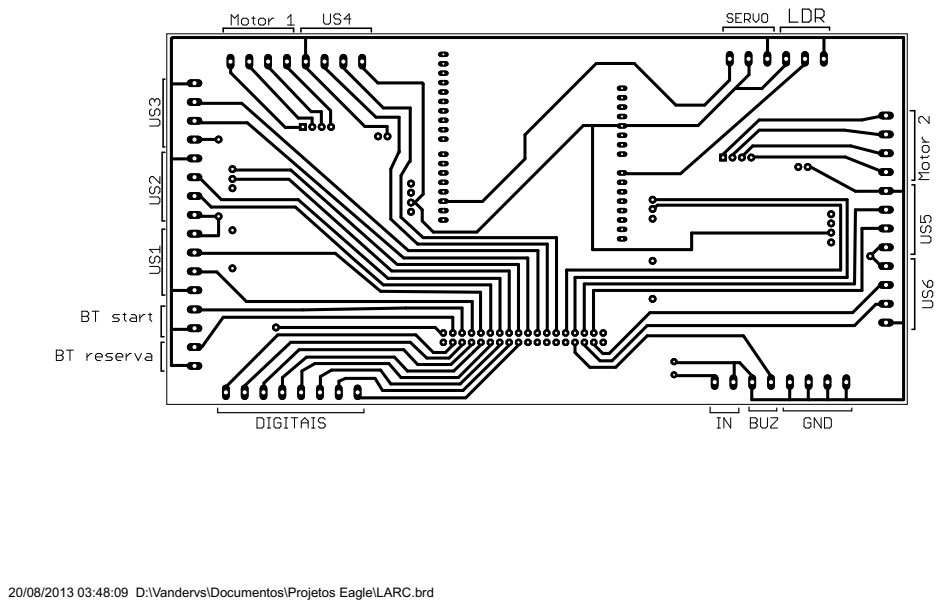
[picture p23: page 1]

20/08/2013 03:48:09 D:\Vandervs\Documentos\Projetos Eagle\LARC.brd

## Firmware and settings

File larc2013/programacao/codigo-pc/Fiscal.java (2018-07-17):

import java.awt.Color;
import java.awt.Font;
import java.awt.Graphics;
import java.awt.event.KeyEvent;
import java.awt.event.KeyListener;
import java.awt.event.MouseEvent;
import java.awt.event.MouseListener;
import java.awt.image.BufferedImage;
import java.io.IOException;
import java.nio.ByteBuffer;
import java.util.Scanner;

import javax.swing.*;


public class Fiscal extends JFrame implements KeyListener, MouseListener, Runnable
{
	private Connection connection;
	private MessageAssembler msgAssembler;
	


	//private final String IP_ANDROID = "192.168.0.172";
	private final String IP_ANDROID = "192.168.43.1";	//galaxy
	private final int PORT_ANDROID = 18550;
	
	public static final int DEFAULT_VELOCITY = 255;
	
	/*private final byte fr1[] = {0x10,(byte) 0xFF,0};
	private final byte fr2[] = {0x11,(byte) 0xFF,1};	
	private final byte tr1[] = {0x10,(byte) 0xFF,1};
	private final String IP_ANDROID = "192.168.0.115
	private final byte tr2[] = {0x11,(byte) 0xFF,0};
	private final byte esq1[] = {0x10,(byte) 0xFF,0};
	private final byte esq2[] = {0x11,(byte) 0xFF,0};
	private final byte dir1[] = {0x10,(byte) 0xFF,1};
	private final byte dir2[] = {0x11,(byte) 0xFF,1};*/
	private final byte forward[] = {0x11,(byte) DEFAULT_VELOCITY, 0, 0x12, (byte) DEFAULT_VELOCITY, 1};
	private final byte backward[] = {0x11,(byte) DEFAULT_VELOCITY, 1,0x12, (byte) DEFAULT_VELOCITY, 0};
	private final byte right[] = {0x11,(byte) DEFAULT_VELOCITY, 1, 0x12, (byte) DEFAULT_VELOCITY, 1};
	private final byte left[] = {0x11,(byte) DEFAULT_VELOCITY, 0, 0x12, (byte) DEFAULT_VELOCITY, 0};
	
	
	private final byte stop1[] = {0x11,0,0,0x12,0,0};
	private final byte stop2[] = {0x11,0,0,0x12,0,0};
	private final byte reqImg[] = {0x61};
	
	private final byte ligaVassoura[] = {0x13,(byte)255,0};
	private final byte desligaVassoura[] = {0x13,0,1};

	private final byte openDeposit[] = {0x14,(byte) 77};
	private final byte closeDeposit[] = {0x14,(byte) 90};
	private final byte offDeposit[] = {0x14,(byte) 90};
	
	private byte imgCalibration[];
	
	private int[] direction;
	private int[] lastDirection;
	
	private int stopping;
	private long stop_time;
	
	private BufferedImage graphicsBuffer;
	private BufferedImage cameraImage;

	private float[] Accelerometer = {0, 0, 0};
	private float[] Compass = {0, 0, 0};
	private int[] Encoder = {0, 0};
	private int[] UltraSound = {0, 0, 0, 0, 0, 0, 0};
	
	private boolean lockRequestImage = false;
	private boolean writeDisk = false;
	private boolean writeMemory = false;
	
	private boolean screen;
	
	private int xClick;
	private int yClick;
	
	private boolean closedClaw = true;
	private boolean openedClaw = false;
	
	private boolean highClaw = true;
	private boolean lowClaw = false;
	
	private boolean openedDeposit = false;
	private boolean closedDeposit = true;
	
	private boolean vassouraRodando = false;
	
	Fiscal()
	{		
		super("Fiscal");
		
		screen = true;
		
		//JFrame f = new JFrame("A JFrame");
		
		imgCalibration = new byte[49];
		
		connection = null;
		
		direction = new int[4];
		lastDirection = new int[4];
		
		for(int i=0; i<4; i++)
		{
			direction[i] = 0;
			lastDirection[i] = 0;
		}
		
		stopping = 0;
		stop_time = 0;
		
		graphicsBuffer = new BufferedImage(800, 400, BufferedImage.TYPE_INT_ARGB);
		cameraImage = null;
	}
	
	public static byte[] toByta(int data) 
	{
	    return new byte[] {
	        (byte)((data >> 24) & 0xff),
	        (byte)((data >> 16) & 0xff),
	        (byte)((data >> 8) & 0xff),
	        (byte)((data >> 0) & 0xff),
	    };
	}
	
	public static byte[] toByta(float data) 
	{
	    return toByta(Float.floatToRawIntBits(data));
	}

	public void connectToAndroid()
	{		
		try
		{
			connection = new Connection(IP_ANDROID, PORT_ANDROID);
			msgAssembler = new MessageAssembler(connection);
		}
		catch (IOException e)
		{
			System.out.println("Couldn't connect to android.");
			e.printStackTrace();
		}
		
	}
	
	public boolean isConnected()
	{
		if(connection == null)
		{
			return false;
		}
		else
		{
			return true;
		}
	}
	
	private void drawCameraImage(Graphics g)
	{
		if(cameraImage != null)
		{
			g.drawImage(cameraImage, 400, 0, 400, 400, null);
			
			int x = xClick-400;
			int y = yClick;
			
			x = x*cameraImage.getWidth()/400;
			y = y*cameraImage.getHeight()/400;
			
			if(x >= 0 && x < cameraImage.getWidth() && y >= 0 && y < cameraImage.getHeight())
			{				
				int rgb = cameraImage.getRGB(x, y);
				Font f = new Font("arial", Font.PLAIN, 14);
				g.setFont(f);				
				g.setColor(Color.BLACK);
				String colorString = (rgb >> 16 & 0x000000FF) + "-" + (rgb >> 8 & 0x000000FF) + "-" + (rgb & 0x000000FF);
				g.drawString(colorString, 200, 40);
			}
		}
	}
	
	public void paint(Graphics gBad)
	{
		Graphics g = graphicsBuffer.getGraphics();
		
		g.setColor(Color.WHITE);
		
		g.fillRect(0, 0, 400, 400);
		
		drawCameraImage(g);
		
				
		g.setColor(Color.BLACK);
		Font f = new Font("arial", Font.PLAIN, 14);
		g.setFont(f);
		
		if(connection == null)
		{
			g.drawString("Waiting for connection", 20, 60);
			
			g.setColor(Color.RED);			
			g.fillRect(100, 100, 100, 100);
			g.drawString("Accelerometer: "+Accelerometer[0]+" ,"+Accelerometer[1]+" ,"+Accelerometer[2], 20, 240);
			g.drawString("Compass: "+(57.3 * Math.atan2(Compass[1], Compass[2])), 20, 260);
			g.drawString("Encoder: "+Encoder[0]+" ,"+Encoder[1], 20, 280);
			g.drawString("Ultrassound: "+UltraSound[0]+" ,"+UltraSound[1]+" ,"+UltraSound[2]+" ,"+UltraSound[3]+" ,"+UltraSound[4]+" ,"+UltraSound[5]+" ,"+UltraSound[6], 20, 300);
			
			g.drawString("Cor 1:", 20, 340);
			g.drawString("Cor 2:", 20, 360);
			g.drawString("Cor 3:", 20, 380);
			g.drawString("Cor 4:", 20, 400);
		}
		else
		{
			g.drawString("Connected", 20, 60);
			
			g.setColor(Color.GREEN);			
			g.fillRect(100, 100, 100, 100);
			
			g.setColor(Color.BLACK);
			g.drawString("Accelerometer: "+Accelerometer[0]+" ,"+Accelerometer[1]+" ,"+Accelerometer[2], 20, 240);
			g.drawString("Compass: "+Compass[0]+" ,"+Compass[1]+" ,"+Compass[2]+" ,"+(57.3 * Math.atan2(Compass[1], Compass[2])), 20, 260);
			g.drawString("Encoder: "+Encoder[0]+" ,"+Encoder[1], 20, 280);
			g.drawString("Ultrassound: "+UltraSound[0]+" ,"+UltraSound[1]+" ,"+UltraSound[2]+" ,"+UltraSound[3]+" ,"+UltraSound[4]+" ,"+UltraSound[5]+" ,"+UltraSound[6], 20, 300);
			ByteBuffer bb = ByteBuffer.allocate(4);
			bb.put(imgCalibration, 9, 4);
			bb.rewind();
			g.drawString("Cor 1:"+"("+(imgCalibration[1]&0xFF)+"|"+(imgCalibration[2]&0xFF)+"|"+(imgCalibration[3]&0xFF)+"|"+(imgCalibration[4]&0xFF)+") ("+(imgCalibration[5]&0xFF)+"|"+(imgCalibration[6]&0xFF)+"|"+(imgCalibration[7]&0xFF)+"|"+(imgCalibration[8]&0xFF)+") ("+bb.getFloat()+")", 20, 320);
			g.setColor(new Color(imgCalibration[1]&0xFF, imgCalibration[2]&0xFF, imgCalibration[3]&0xFF));			
			g.fillRect(300, 306, 16, 16);
			g.setColor(Color.BLACK);
			g.drawRect(300, 306, 16, 16);
			
			bb.rewind();
			bb.put(imgCalibration, 21, 4);
			bb.rewind();
			g.drawString("Cor 2:"+"("+(imgCalibration[13]&0xFF)+"|"+(imgCalibration[14]&0xFF)+"|"+(imgCalibration[15]&0xFF)+"|"+(imgCalibration[16]&0xFF)+") ("+(imgCalibration[17]&0xFF)+"|"+(imgCalibration[18]&0xFF)+"|"+(imgCalibration[19]&0xFF)+"|"+(imgCalibration[20]&0xFF)+") ("+bb.getFloat()+")", 20, 340);
			g.setColor(new Color(imgCalibration[13]&0xFF, imgCalibration[14]&0xFF, imgCalibration[15]&0xFF));			
			g.fillRect(300, 326, 16, 16);
			g.setColor(Color.BLACK);
			g.drawRect(300, 326, 16, 16);
			
			bb.rewind();
			bb.put(imgCalibration, 33, 4);
			bb.rewind();
			g.drawString("Cor 3:"+"("+(imgCalibration[25]&0xFF)+"|"+(imgCalibration[26]&0xFF)+"|"+(imgCalibration[27]&0xFF)+"|"+(imgCalibration[28]&0xFF)+") ("+(imgCalibration[29]&0xFF)+"|"+(imgCalibration[30]&0xFF)+"|"+(imgCalibration[31]&0xFF)+"|"+(imgCalibration[32]&0xFF)+") ("+bb.getFloat()+")", 20, 360);
			g.setColor(new Color(imgCalibration[25]&0xFF, imgCalibration[26]&0xFF, imgCalibration[27]&0xFF));			
			g.fillRect(300, 346, 16, 16);
			g.setColor(Color.BLACK);
			g.drawRect(300, 346, 16, 16);
			
			bb.rewind();
			bb.put(imgCalibration, 45, 4);
			bb.rewind();
			g.drawString("Cor 4:"+"("+(imgCalibration[37]&0xFF)+"|"+(imgCalibration[38]&0xFF)+"|"+(imgCalibration[39]&0xFF)+"|"+(imgCalibration[40]&0xFF)+") ("+(imgCalibration[41]&0xFF)+"|"+(imgCalibration[42]&0xFF)+"|"+(imgCalibration[43]&0xFF)+"|"+(imgCalibration[44]&0xFF)+") ("+bb.getFloat()+")", 20, 380);
			g.setColor(new Color(imgCalibration[37]&0xFF, imgCalibration[38]&0xFF, imgCalibration[39]&0xFF));			
			g.fillRect(300, 366, 16, 16);
			g.setColor(Color.BLACK);
			g.drawRect(300, 366, 16, 16);
		}
		
		gBad.drawImage(graphicsBuffer, 0, 0, 800, 400, null);
		
	}
	
	public void start()
	{
		new Thread(this).start();
		new Thread(this).start();
	}
	
	public synchronized void sendMovementMessage()
	{				
		try 
		{
			if(direction[0] == 1 && lastDirection[0] == 0)
			{
				//connection.sendMessage(esq1, 0, 3);
				//connection.sendMessage(esq2, 0, 3);
				connection.sendMessage(left, 0, 6);
				stopping = 0;
				
				//System.out.println("1 "+System.currentTimeMillis());
			}
			else if(direction[1] == 1 && lastDirection[1] == 0)
			{
				//connection.sendMessage(fr1, 0, 3);
				//connection.sendMessage(fr2, 0, 3);
				connection.sendMessage(forward, 0, 6);
				stopping = 0;
				
				//System.out.println("2 "+System.currentTimeMillis());
			}
			else if(direction[2] == 1 && lastDirection[2] == 0)
			{
				//connection.sendMessage(dir1, 0, 3);
				//connection.sendMessage(dir2, 0, 3);				
				connection.sendMessage(right, 0, 6);
				stopping = 0;
				
				//System.out.println("3 "+System.currentTimeMillis());
			}
			else if(direction[3] == 1 && lastDirection[3] == 0)
			{				
				//connection.sendMessage(tr1, 0, 3);
				//connection.sendMessage(tr2, 0, 3);
				connection.sendMessage(backward, 0, 6);
				stopping = 0;
				
				//System.out.println("4 "+System.currentTimeMillis());
			}
			else if(direction[0] == 0 && direction[1] == 0 &&
					direction[2] == 0 && direction[3] == 0)					
			{
				if(stopping == 0)
				{
					stopping = 1;
					stop_time = System.currentTimeMillis();
				}
				else if(stopping == 1 && System.currentTimeMillis() - stop_time > 10)
				{
					stopping = 2;
					connection.sendMessage(stop1, 0, 6);
					connection.sendMessage(stop2, 0, 6);				
				
					//System.out.println("5 "+System.currentTimeMillis());
				}
							
			}
			else
			{
				stopping = 0;	// Fuck you Java, fuck you
			}
		}
		catch (Exception e) 
		{
			e.printStackTrace();
		}	
		
		for(int i=0; i<4; i++)
		{
			lastDirection[i] = direction[i];
		}
	}
	
	private BufferedImage retrieveImage(byte[] cameraMsg)
	{
		int code = cameraMsg[0] & 0xFF;
		
		if(code != 0x60)
		{
			System.out.println("This message is not a camera msg!");
		}
		
		ByteBuffer bb = ByteBuffer.allocate(12);	
		bb.put(cameraMsg, 1, 12);
		
		bb.rewind();
		
		int width = bb.getInt();
		int height = bb.getInt();
		//int dataLength = bb.getInt();
		
        int frameSize = width * height;                        
        int[] rgba = new int[frameSize];
        
        for (int i = 0; i < height; i++)
        {
            for (int j = 0; j < width; j++) 
            {
            	int index = i * width + j;
            	
            	int r = cameraMsg[3 * index + 2 + 13];
            	int g = cameraMsg[3 * index + 1 + 13];
            	int b = cameraMsg[3 * index + 0 + 13];
            	
            	rgba[index] = 0xff000000 + (b << 16) + (g << 8) + r;
            }            
        }
       
        /*
        boolean grayscale = false;
        if (grayscale) 
        {
            for (int i = 0; i < frameSize; i++) 
            {
                int y = (0xff & ((int) cameraMsg[i + 13]));
                rgba[i] = 0xff000000 + (y << 16) + (y << 8) + y;
            }
        } 
        else
        {
            for (int i = 0; i < height; i++)
            {
                for (int j = 0; j < width; j++) 
                {
                	int index = i * width + j;
                	int supply_index = frameSize + (i >> 1) * width + (j & ~1);
                    int y = (0xff & ((int) cameraMsg[index + 13]));
                    int u = (0xff & ((int) cameraMsg[supply_index + 0 + 13]));
                    int v = (0xff & ((int) cameraMsg[supply_index + 1 + 13]));
                    y = y < 16 ? 16 : y;
                    
                    float y_conv = 1.164f * (y - 16);
                    int r = Math.round(y_conv + 1.596f * (v - 128));
                    int g = Math.round(y_conv - 0.813f * (v - 128) - 0.391f * (u - 128));
                    int b = Math.round(y_conv + 2.018f * (u - 128));

                    r = r < 0 ? 0 : (r > 255 ? 255 : r);
                    g = g < 0 ? 0 : (g > 255 ? 255 : g);
                    b = b < 0 ? 0 : (b > 255 ? 255 : b);

                    rgba[i * width + j] = 0xff000000 + (b << 16) + (g << 8) + r;
                }
            }
        }
        */
        		
        //BufferedImage img = new BufferedImage(width, height, BufferedImage.TYPE_INT_ARGB);
        //img.setRGB(0, 0, width, height, rgba, 0, width);
        
		BufferedImage img = new BufferedImage(width, height, BufferedImage.TYPE_INT_ARGB);
        img.setRGB(0, 0, width, height, rgba, 0, width);      
		
        return img;
	}

	private float[] retrieveAccelerometer(byte[] AccelerometerMsg)
	{
		//int code = AccelerometerMsg[0] & 0xFF;
				
		ByteBuffer bb = ByteBuffer.allocate(12);
		
		bb.put(AccelerometerMsg, 1, 12);
		bb.rewind();
		float dataX = bb.getFloat();
		float dataY = bb.getFloat();
		float dataZ = bb.getFloat();
		
		float accel[] = {dataX, dataY, dataZ};
		return accel;
	}

	private float[] retrieveCompass(byte[] CompassMsg)
	{
		//int code = CompassMsg[0] & 0xFF;
		
		ByteBuffer bb = ByteBuffer.allocate(12);
		
		bb.put(CompassMsg, 1, 12);
		bb.rewind();
		float dataX = bb.getFloat();
		float dataY = bb.getFloat();
		float dataZ = bb.getFloat();
		
		float comp[] = {dataX, dataY, dataZ};
		return comp;
	}
	
	private int[] retrieveEncoder(byte[] EncoderMsg)
	{
		//int code = EncoderMsg[0] & 0xFF;
		
		ByteBuffer bb = ByteBuffer.allocate(8);
		
		bb.put(EncoderMsg, 1, 8);
		bb.rewind();
		int dataRight = bb.getInt();
		int dataLeft = bb.getInt();
		
		int comp[] = {dataRight, dataLeft};
		//System.out.println(dataRight+" "+dataLeft);
		return comp;
	}
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
	public static void main(String[] args) 
	{
		Fiscal tela = new Fiscal();
		tela.setSize(800, 400);
		//tela.setLocation(300,200);
		//f.getContentPane().add(BorderLayout.CENTER, new JTextArea(10, 40));
		tela.addKeyListener(tela);
		tela.addMouseListener(tela);
		tela.setVisible(true);
		tela.connectToAndroid();
		tela.repaint();
		tela.start();
		
	}

	public synchronized void keyPressed(KeyEvent event)
	{		
		switch(event.getKeyCode())
		{
			case 37:
			{
				direction[0] = 1;
			}break;
			
			case 38:
			{
				direction[1] = 1;	
			}break;
			
			case 39:
			{
				direction[2] = 1;
			}break;
			
			case 40:
			{
				direction[3] = 1;
			}break;
			case 80://p
			{
				if(!lockRequestImage)
				{
					lockRequestImage = true;
					sendRequestReceiveImage();
				}
			}break;
			case 87://w -> write in disk
			{
				if(!writeDisk)
				{
					writeDisk = true;
					imgCalibration[0] = 0x62;
					sendRequestWriteDisk();
				}
			}break;
			case 83://s -> write in memory
			{
				if(!writeMemory)
				{
					writeMemory = true;
					imgCalibration[0] = 0x63;
					sendRequestWriteMemory();
				}
			}break;
			
			case 86://v -> liga ou desliga a vassoura
			{
				System.out.println("Vassoura");
				
				if(vassouraRodando)
				{
					vassouraRodando = false;
					sendRequestDesligaVassoura();
				} else {
					vassouraRodando = true;
					sendRequestLigaVassoura();
				}
				
			}break;
			
			case 69: // 'e'
			{
				if (openedDeposit)
				{
					openedDeposit = false;
					closedDeposit = true;
					sendRequestCloseDeposit();
				}
				
			}break;
			case 70: // 'f'
			{
				if (closedDeposit)
				{
					openedDeposit = true;
					closedDeposit = false;
					sendRequestOpenDeposit();
				}
			}break;
			
			
		}
		
		//System.out.println(event.getKeyCode() + " " + event.getWhen());
	}

	public synchronized void keyReleased(KeyEvent event) 
	{	
		switch(event.getKeyCode())
		{
			case 37:
			{
				direction[0] = 0; 
			}break;
			
			case 38:
			{
				direction[1] = 0;
			}break;
			
			case 39:
			{
				direction[2] = 0;
			}break;
			
			case 40:
			{
				direction[3] = 0;
			}break;
			case 80://p
			{
				lockRequestImage = false;
			}break;
			case 87://w -> write in disk
			{
				writeDisk = false;
			}break;
			case 83://s -> write in memory
			{
				writeMemory = false;
			}break;
			case 69: // 'e'
			{
				//sendRequestOffDeposit();
				
			}break;
			case 70: // 'f' 
			{
				//sendRequestOffDeposit();
			}break;
			case 76: // 'v' 
			{
			//	vassoura
			}break;
			case 67: // 'c'
			{
			//	sendRequestStopClaw();
			}break;
			case 85: // 'u' 
			{
			//	sendRequestStopClaw2();	
			}break;
			
			case 68: // 'd'
			{
			//	sendRequestStopClaw2();
			}break;
		}			
			
		//System.out.println(event.getKeyCode() + "tete " + event.getWhen());
		
	}

	public void keyTyped(KeyEvent event) 
	{		
	}
	
	public void sendRequestReceiveImage()
	{
		try {
			connection.sendMessage(reqImg, 0, 1);
		} catch (IOException e) {
			// TODO Auto-generated catch block
			e.printStackTrace();
		}
	}
	
	public void sendRequestWriteDisk()
	{
		try {
			connection.sendMessage(imgCalibration, 0, 49);
		} catch (IOException e) {
			// TODO Auto-generated catch block
			e.printStackTrace();
		}
	}
	
	public void sendRequestWriteMemory()
	{
		try {
			connection.sendMessage(imgCalibration, 0, 49);
		} catch (IOException e) {
			// TODO Auto-generated catch block
			e.printStackTrace();
		}
	}
	
	
	public void sendRequestOpenDeposit()
	{
		try {
			connection.sendMessage(openDeposit, 0, 2);
		} catch (IOException e) {
			// TODO Auto-generated catch block
			e.printStackTrace();
		}
	}
	
	public void sendRequestLigaVassoura()
	{
		try {
			connection.sendMessage(ligaVassoura, 0, 3);
		} catch (IOException e) {
			// TODO Auto-generated catch block
			e.printStackTrace();
		}
	}
	
	public void sendRequestDesligaVassoura()
	{
		try {
			connection.sendMessage(desligaVassoura, 0, 3);
		} catch (IOException e) {
			// TODO Auto-generated catch block
			e.printStackTrace();
		}
	}
	
	public void sendRequestCloseDeposit()
	{
		try {
			connection.sendMessage(closeDeposit, 0, 2);
		} catch (IOException e) {
			// TODO Auto-generated catch block
			e.printStackTrace();
		}
	}
	
	public void sendRequestOffDeposit()
	{
		try {
			connection.sendMessage(offDeposit, 0, 2);
		} catch (IOException e) {
			// TODO Auto-generated catch block
			e.printStackTrace();
		}
	}
	
	public void setColorReceived(byte[] msg)
	{
		//ByteBuffer bb = ByteBuffer.allocate(4);
		//bb.put(msg,1,48);
		
		for(int i = 0; i<49; i++)
		{
			imgCalibration[i] = msg[i]; 
		}
	}
	public void buildColor()
	{
		imgCalibration[0] = 0x62;
		
		for (int i = 1; i < 49; i++)
		{
			imgCalibration[i] = 1;
		}
		
	}

	@Override
	public void mouseClicked(MouseEvent arg0) 
	{
		xClick = arg0.getX();
		yClick = arg0.getY();
		this.repaint();
	}

	@Override
	public void mouseEntered(MouseEvent arg0) {
		// TODO Auto-generated method stub
		
	}

	@Override
	public void mouseExited(MouseEvent arg0) {
		// TODO Auto-generated method stub
		
	}

	@Override
	public void mousePressed(MouseEvent arg0) {
		// TODO Auto-generated method stub
		
	}

	@Override
	public void mouseReleased(MouseEvent arg0) {
		// TODO Auto-generated method stub
		
	}

}

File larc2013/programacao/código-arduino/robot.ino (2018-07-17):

/* Argumento[0]: Funcionamento do Robo (0 desligada, 1 ligada)
 * Argumento[1]: Estado do robo
 * Argumento[2]: Velocidade (0 a 5)
 * Argumento[3]: Corresponde ao funcionamento da vassoura (0 desligada, 1 ligada)
 * Argumento[4]: Corresponde ao despejo das latas (0 parado, 1 abrindo, 2 fechando)
 * Argumento[5]: Corresponde ao vibrador (0 desligada, 1 ligada)
 
 * LISTA DE ESTADOS DO ROBO
 * 0 Totalmente parado
 * 1 Andando para frente
 * 2 Andando para traz
 * 3 Curvando para esquerda andando pra frente
 * 4 Curvando para direita andando pra frente
 * 5 Girando (no mesmo lugar - 360º) para esquerda
 * 6 Girando (no mesmo lugar - 360º) para direita
 * 7 Curvando para esquerda andando pra traz
 * 8 Curvando para direita andando pra traz

*/


#include <Adb.h>
#include <SPI.h>
#include <Servo.h>

//Pinos dos Motores para Movimentação
#define DIR_R 46 //Direita
#define PWM_R 9 
#define DIR_L 48 //Esquerda
#define PWM_L 10

//Pinos do Motor da Vassoura
#define DIR_VAS 34
#define PWM_VAS 11

#define PIN_VIB 23 //VIBRADOR
#define PIN_SERVO 2

Servo servo;
uint8_t Estado[6]; //Vetor de Estados
int motorPWMPins[3] = {PWM_R, PWM_L, PWM_VAS};
int motorDirPins[3] = {DIR_R, DIR_L, DIR_VAS};

Connection * connection;

void setMotor(int motor, uint8_t velocity, uint8_t direction)
{

	if(direction)
	{
		digitalWrite(motorDirPins[motor], HIGH);
	}
	else
	{
		digitalWrite(motorDirPins[motor], LOW);
	}	

	analogWrite(motorPWMPins[motor], velocity);
}

void setup()
{
  Serial.begin(57600); //inicia a porta serial 
  
	pinMode(DIR_R,OUTPUT);
	pinMode(PWM_R,OUTPUT);
	pinMode(DIR_L,OUTPUT);
	pinMode(PWM_L,OUTPUT);
	pinMode(DIR_VAS,OUTPUT);
	pinMode(PWM_VAS,OUTPUT);
	pinMode(PIN_VIB, OUTPUT);
	servo.attach(2);
	
	setMotor(0, 0, 1);
	setMotor(1, 0, 1);
	setMotor(2, 0, 1);
	digitalWrite(PIN_VIB, LOW);
	servo.write(90);
 
	ADB::init();
	connection = ADB::addConnection("tcp:4568", true, adbEventHandler);  
}

void loop()
{
	uint8_t velocity;
	ADB::poll();

	if(Estado[0])
	{
		//Motores para movimento
		velocity = 63*Estado[2];
		
		if(Estado[1] == 0)
		{
			setMotor(0, 0, 1);
			setMotor(1, 0, 1);
		}
		if(Estado[1] == 1)
		{
			setMotor(0, velocity, 1);
			setMotor(1, velocity, 1);
		}
		if(Estado[1] == 2)
		{
			setMotor(0, velocity, 0);
			setMotor(1, velocity, 0);
		}
		if(Estado[1] == 3)
		{
			setMotor(0, velocity, 1);
			setMotor(1, velocity/2, 1);
		}
		if(Estado[1] == 4)
		{
			setMotor(0, velocity/2, 1);
			setMotor(1, velocity, 1);
		}
		if(Estado[1] == 5)
		{
			setMotor(0, velocity, 1);
			setMotor(1, velocity, 0);
		}
		if(Estado[1] == 6)
		{
			setMotor(0, velocity, 0);
			setMotor(1, velocity, 1);
		}
		if(Estado[1] == 7)
		{
			setMotor(0, velocity/2, 0);
			setMotor(1, velocity, 0);
		}
		if(Estado[1] == 8)
		{
			setMotor(0, velocity, 0);
			setMotor(1, velocity/2, 0);
		}
		
		//vassoura
		if(Estado[3] == 1)
			setMotor(2, 250, 1);
		else
			setMotor(2, 0, 1);
			
		//comporta
		if(Estado[4] == 0 || Estado[4] == 2)
			servo.write(90);
		if(Estado[4] == 1)
			servo.write(77);
			
		//vibrador
		if(Estado[5] == 1)
			digitalWrite(PIN_VIB, HIGH);
		else
			digitalWrite(PIN_VIB, LOW);
	} else {
		setMotor(0, 0, 1);
		setMotor(1, 0, 1);
		setMotor(2, 0, 1);
		digitalWrite(PIN_VIB, LOW);
		servo.write(90);
	}

}

void adbEventHandler(Connection * connection, adb_eventType event, uint16_t length, uint8_t * data)
{
	if (event == ADB_CONNECTION_RECEIVE)   // If recieve data
	{
		for(int i = 0; i < 6; i++)
			Estado[i] = data[i];
        Serial.print(Estado[0]);
		Serial.print(" , ");
		Serial.print(Estado[1]);
		Serial.print(" , ");
		Serial.print(Estado[2]);
		Serial.print(" , ");
		Serial.print(Estado[3]);
		Serial.print(" , ");
		Serial.print(Estado[4]);
		Serial.print(" , ");
		Serial.println(Estado[5]);
		
	}
}
